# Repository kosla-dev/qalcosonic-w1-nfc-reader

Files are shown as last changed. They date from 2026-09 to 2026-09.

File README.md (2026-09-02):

# Qalcosonic W1 NFC Reader

A compact ESPHome-based NFC reader for the **Qalcosonic W1** water meter, built around a **Seeed Studio XIAO ESP32-C3**, **PN5180** ISO15693 reader and a custom adapter PCB.

The reader exposes water consumption, flow, temperature, battery state and meter diagnostics to Home Assistant without a camera or OCR pipeline.

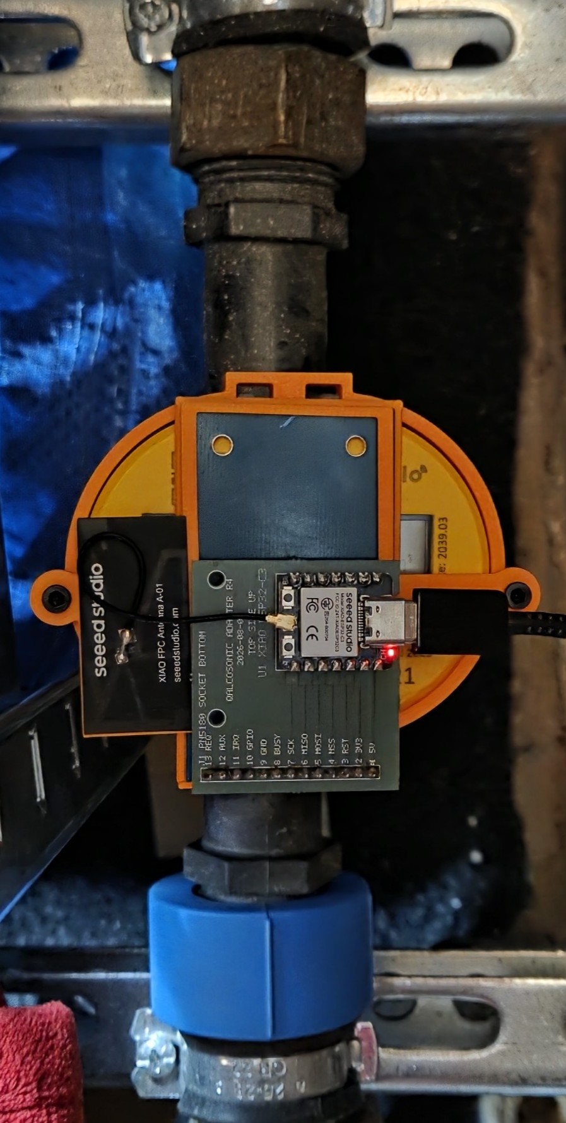
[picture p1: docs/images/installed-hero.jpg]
Installed Qalcosonic W1 NFC reader


## What you need

- Qalcosonic W1 water meter
- PN5180 NFC reader module
- Standard 2.54 mm male pin header strip for the PN5180 ↔ adapter PCB connection (usually included with the PN5180 module)
- Seeed Studio XIAO ESP32-C3
- Custom PN5180 ↔ XIAO adapter PCB
- Three printed R1.0 mechanical parts
- 2 × M3 × 8 mm pan-head screws

The current R1.0 mechanical design has been physically test-printed, assembled and used on a real Qalcosonic W1.

## Quick start

1. Order or manufacture the adapter PCB from [`hardware/`](hardware/).
2. Print the mechanical parts from [`mechanical/`](mechanical/).
3. Assemble the XIAO ESP32-C3, adapter PCB and PN5180.
4. Flash [`firmware/qalcosonic-w1-nfc-reader.yaml`](firmware/qalcosonic-w1-nfc-reader.yaml) with ESPHome.
5. Install the reader on the meter using the supplied R1.0 orientation.
6. Add the ESPHome device to Home Assistant.

Detailed instructions are under [`docs/`](docs/).

## Firmware

The production configuration uses ESPHome **2026.8.2 or newer** and the external [`dbmaxpayne/esphome_qalcosonicnfc`](https://github.com/dbmaxpayne/esphome_qalcosonicnfc) component pinned to:

```text
bed6773b803a7ebf71613585aad8a73376d38b8e
```

The meter is polled every **5 minutes**. Primary water data and important error states are enabled by default; lower-level diagnostic data remains disabled by default.

See [`firmware/`](firmware/) for the configuration and secrets template.

## Mechanical design

The clean-sheet R1.0 mount consists of:

1. meter collar / base
2. PN5180 carrier
3. upper retainer

The PN5180 PCB is retained with two M3 × 8 mm screws. All three printed parts are designed to print without slicer-generated supports.

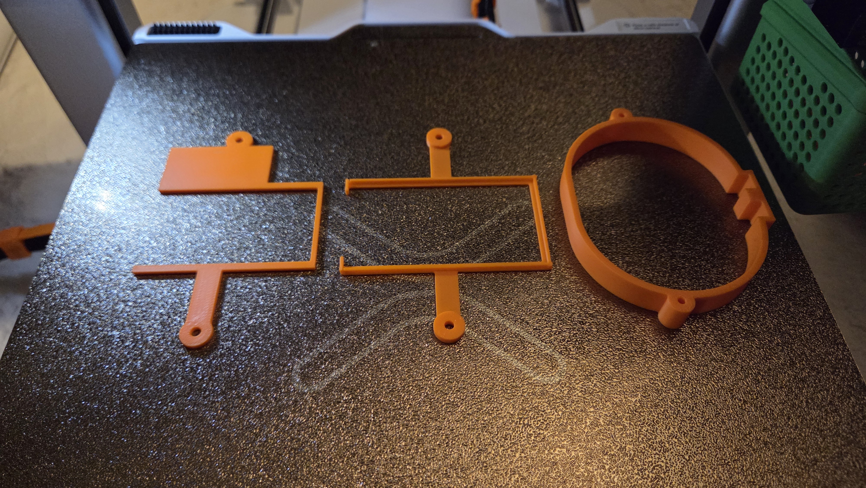
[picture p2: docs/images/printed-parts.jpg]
Printed R1.0 parts


Ready-to-print and editable files are under [`mechanical/`](mechanical/).

The ready-to-download R1.0 model is also available on [Printables](https://www.printables.com/model/1829911-qalcosonic-w1-pn5180-nfc-reader-mount).

## PCB

The custom 2-layer adapter PCB connects the XIAO ESP32-C3 directly to the PN5180. Gerber/Excellon files and an AISLER-ready ZIP are under [`hardware/`](hardware/).

PCB photographs are illustrative. The checked-in Revision 3 manufacturing files are the fabrication source of truth.

## Printing

Recommended starting point:

- 0.4 mm nozzle
- 0.20 mm layer height
- 3 walls
- 20% grid or gyroid infill
- supports: **OFF**
- PETG recommended for long-term installation
- PLA suitable for fit and function testing

See [`mechanical/README.md`](mechanical/README.md) for part orientation and package contents.

## Documentation

- [`docs/assembly.md`](docs/assembly.md) — assembly
- [`docs/wiring.md`](docs/wiring.md) — signal mapping
- [`docs/esphome-installation.md`](docs/esphome-installation.md) — ESPHome setup
- [`docs/home-assistant.md`](docs/home-assistant.md) — Home Assistant integration
- [`docs/troubleshooting.md`](docs/troubleshooting.md) — common checks

## Repository layout

```text
firmware/      ESPHome configuration and example secrets
hardware/      PCB manufacturing files and documentation
mechanical/    3D design source and production package
docs/          Build and installation documentation
LICENSES/      License texts and scope
```

## Support this project

If this project helped you, you can support future development on [Buy Me a Coffee](https://buymeacoffee.com/kosla).

## Licensing

This repository uses scoped licenses:

- firmware/configuration: **MIT**
- PCB and mechanical design assets: **CERN-OHL-P-2.0**
- documentation and project photographs: **CC BY 4.0**

The external `dbmaxpayne/esphome_qalcosonicnfc` dependency remains under its upstream **LGPL-2.1** license.

See [`LICENSE`](LICENSE), [`LICENSES/README.md`](LICENSES/README.md) and [`ATTRIBUTION.md`](ATTRIBUTION.md).

## Disclaimer

This project is provided **as-is**, without warranty of any kind.

Use and installation are entirely at your own risk. The project author is not responsible for damage to equipment, property, water meters or electronics, loss of data, incorrect meter readings, or other consequences resulting from building, installing or using this project.

Always follow applicable local regulations and the requirements of your water utility or meter owner. Do not interfere with metrology seals, certified measurement functions or utility-owned equipment.

This is an independent community project and is not affiliated with or endorsed by Axioma Metering, Seeed Studio, NXP, ESPHome or any utility provider.

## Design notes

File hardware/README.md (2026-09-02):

# Hardware

The reader uses a custom adapter PCB between the **PN5180** NFC module and a **Seeed Studio XIAO ESP32-C3**.

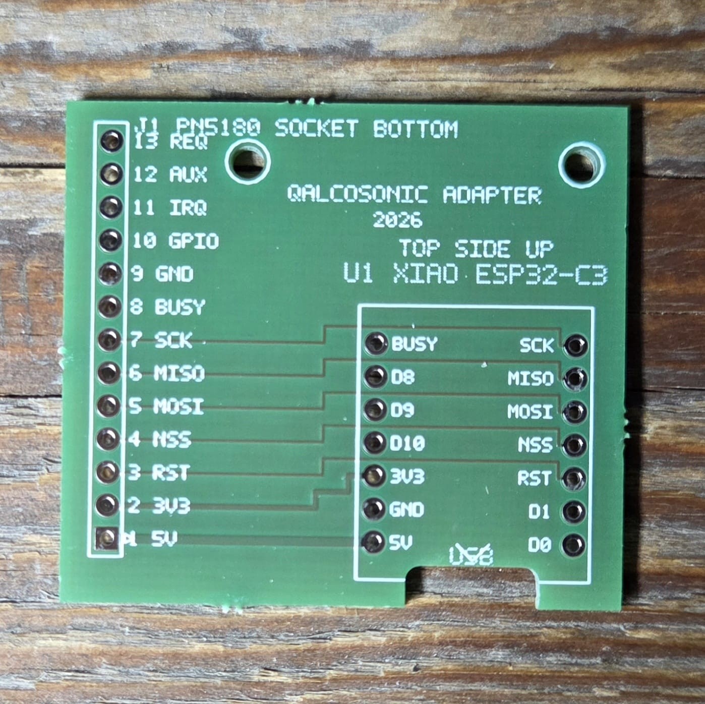
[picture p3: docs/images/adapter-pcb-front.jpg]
Adapter PCB front


> PCB photographs are illustrative. Use the checked-in Revision 3 manufacturing files for fabrication.

## Core hardware

- Seeed Studio XIAO ESP32-C3
- PN5180 NFC reader module
- Standard 2.54 mm male pin header strip for the PN5180 ↔ adapter PCB connection
- Custom 2-layer adapter PCB
- 3D-printed R1.0 meter mount

The pin header is usually included with the PN5180 module. If your module is supplied without one, use a standard 2.54 mm male pin header strip cut to the required length.

| Adapter PCB back | XIAO ESP32-C3 | PN5180 |
|---|---|---|
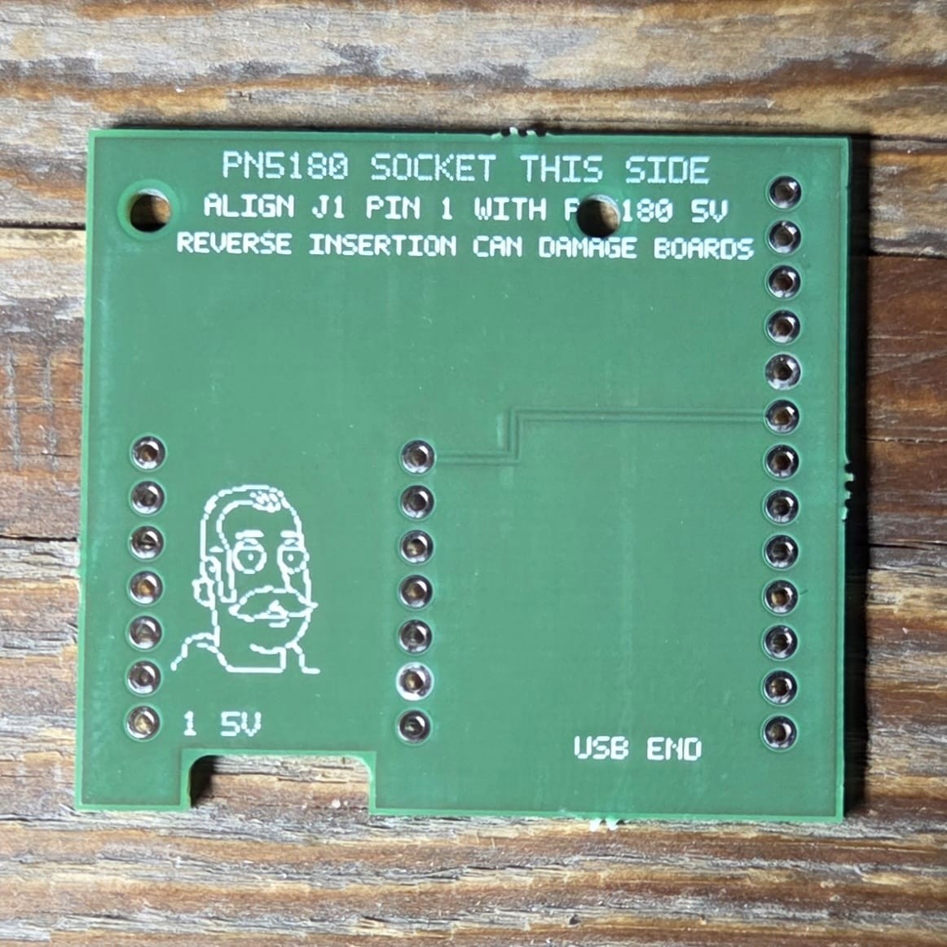
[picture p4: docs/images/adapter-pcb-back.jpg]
Adapter PCB back
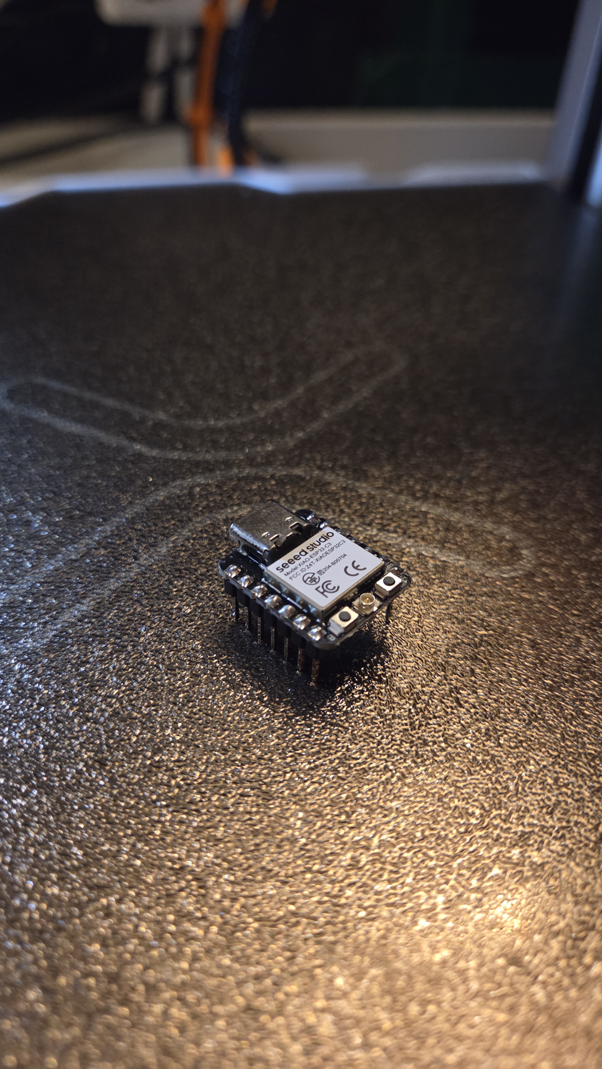
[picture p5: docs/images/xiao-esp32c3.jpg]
XIAO ESP32-C3
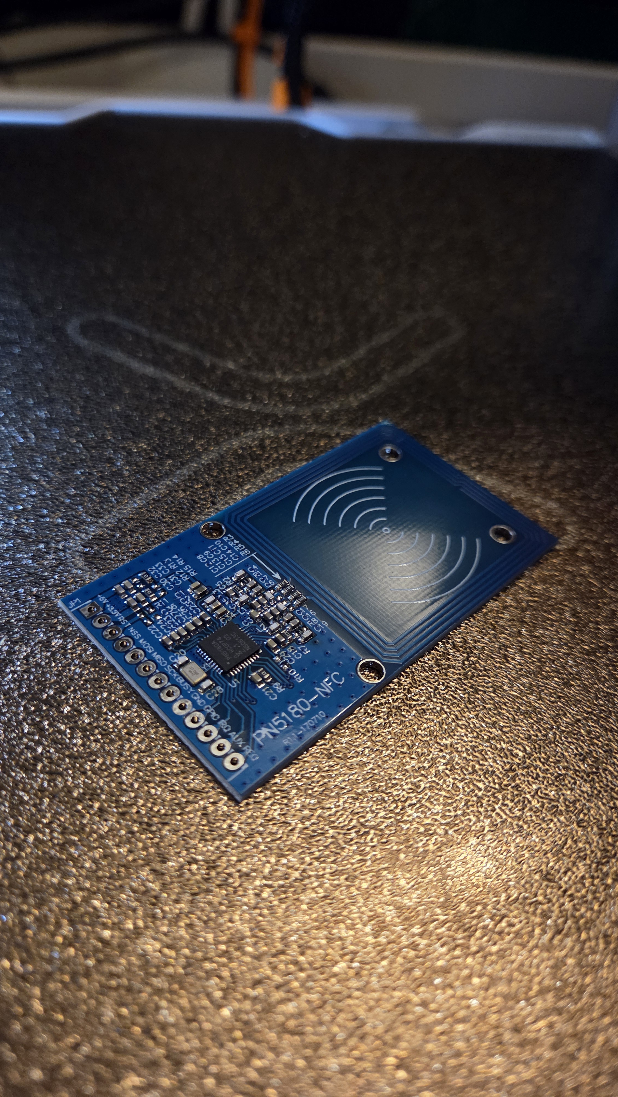
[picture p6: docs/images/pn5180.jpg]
PN5180
|  |  |  |

## Pin mapping

| Signal | XIAO ESP32-C3 |
|---|---:|
| PN5180 MOSI | GPIO6 |
| PN5180 MISO | GPIO7 |
| PN5180 SCK | GPIO21 |
| PN5180 NSS | GPIO5 |
| PN5180 BUSY | GPIO20 |
| PN5180 RST | GPIO4 |

This pinout matches the production ESPHome configuration under `firmware/`.

## PCB production specification

- Layers: 2
- PCB thickness: 1.6 mm
- Copper: 35 µm
- Surface finish: lead-free HASL
- Solder mask: green
- Silkscreen: white
- Stencil: not required for the hand-assembled build

## Manufacturing files

- `hardware/gerbers/` — complete Gerber/Excellon fabrication set
- `hardware/manufacturing/qalcosonic-w1-nfc-reader-pcb-rev3-aisler.zip` — AISLER-ready archive

See [`manufacturing/README.md`](manufacturing/README.md) for the fabrication notes.

Always inspect the board-house preview before placing an order.

## Assembly notes

Before applying power:

1. Inspect solder joints for bridges.
2. Verify 3.3 V and GND are not shorted.
3. Confirm the XIAO and PN5180 orientation.
4. Check signal routing against the pin table above.
5. Power the board on the bench and check for abnormal heating before installing it on the meter.

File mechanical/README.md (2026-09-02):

# Mechanical design

The production design is a clean-sheet, three-part mount for the Qalcosonic W1 and PN5180.

## Parts

### Base / meter collar

Clips around the Qalcosonic W1 and fixes the orientation of the complete reader assembly.

### PN5180 carrier

Locates the 70 × 39 mm PN5180 PCB by its perimeter while keeping the antenna area open.

### Upper retainer

Clamps the PN5180 gently at the PCB edges using two M3 screws and provides the electronics mounting land.

The side wing on the retainer also provides a convenient mounting surface for the external XIAO ESP32-C3 Wi-Fi antenna. The antenna can be attached flat to the wing using its adhesive backing or thin double-sided tape, as shown in the installed project photographs.

## Key dimensions

- Collar engagement: 11.0 mm
- PN5180 PCB reference outline: 70.0 × 39.0 mm
- PCB thickness used for the design: 1.65 mm
- Nominal PCB side clearance: 0.30 mm per side
- Nominal component-to-meter gap: 0.55 mm

## Editable source

The authoritative CadQuery source is:

```text
mechanical/source/qalcosonic_w1_pn5180_production_r1_0.py
```

It exports the base, carrier and retainer geometry.

## Ready-to-print file

The three-part print plate is:

```text
mechanical/3mf/qalcosonic-w1-pn5180-production-r1.0.3mf
```

## Production package

A user-facing package is included as:

```text
mechanical/qalcosonic-w1-pn5180-production-r1.0.zip
```

It contains:

```text
QALCOSONIC_W1_PN5180_R1.0_PRINT_PLATE.3mf
BASE.step
CARRIER.step
RETAINER.step
README.md
```

The 3MF is ready to print. STEP files are included for inspection and modification. The CadQuery source and validation data are also available in the repository.

## Print orientation

- Base: upright with the collar axis in Z
- Carrier: flat
- Retainer: flat
- Supports: **OFF**
- Brim: normally **OFF**

## Recommended settings

- PETG recommended for long-term installation
- PLA suitable for fit/function testing
- 0.4 mm nozzle
- 0.20 mm layer height
- 3 walls
- 5 top / 5 bottom layers
- 20% grid or gyroid infill
- Supports OFF

## Hardware

- 2 × M3 × 8 mm pan-head screws
- No nuts required

Tighten only until the retainer is seated. Do not bow the PN5180 PCB.

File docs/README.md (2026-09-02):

# Documentation

Build and installation documentation for the Qalcosonic W1 NFC Reader.

- [`assembly.md`](assembly.md) — electronics and mechanical assembly
- [`wiring.md`](wiring.md) — XIAO ESP32-C3 ↔ PN5180 signal mapping
- [`esphome-installation.md`](esphome-installation.md) — ESPHome setup and flashing
- [`home-assistant.md`](home-assistant.md) — Home Assistant integration and entity notes
- [`troubleshooting.md`](troubleshooting.md) — common failure modes and checks
- `images/` — project photographs

The documentation is written for the R1.0 production mechanical design.

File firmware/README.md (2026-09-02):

# Firmware

The production firmware is an ESPHome configuration for the **Seeed Studio XIAO ESP32-C3** and PN5180 NFC reader.

## Files

- `qalcosonic-w1-nfc-reader.yaml` — sanitized production configuration
- `secrets.example.yaml` — template for local ESPHome secrets

The configuration uses DHCP by default. If you want a static address, assign one in your router or add your own `manual_ip:` block locally.

## Requirements

- ESPHome **2026.8.2 or newer**
- Seeed Studio XIAO ESP32-C3
- PN5180 module
- Custom adapter PCB or equivalent wiring

## External component

The configuration uses:

`https://github.com/dbmaxpayne/esphome_qalcosonicnfc`

Pinned revision:

```text
bed6773b803a7ebf71613585aad8a73376d38b8e
```

Pinning the dependency keeps builds reproducible.

## Setup

1. Copy `qalcosonic-w1-nfc-reader.yaml` into your ESPHome configuration directory.
2. Copy `secrets.example.yaml` to `secrets.yaml`.
3. Replace all placeholder values in `secrets.yaml`.
4. Compile and flash the XIAO ESP32-C3.
5. Add the discovered ESPHome device to Home Assistant.

The configuration uses `Europe/Helsinki` for the optional meter timepoint sensor. Change it locally if needed.

See [`../docs/wiring.md`](../docs/wiring.md) for the pin mapping and [`../docs/esphome-installation.md`](../docs/esphome-installation.md) for flashing instructions.

## Production behavior

- Meter read interval: **300 s / 5 min**
- Five consecutive read failures are allowed before measurement sensors are treated as unavailable
- `Force Sensor Update` button for manual reads
- ESP32 diagnostics grouped into a separate Home Assistant device
- Primary water data and important error flags enabled by default
- Secondary/raw meter data and most network-identification diagnostics disabled by default
- Normal logging level: `INFO`

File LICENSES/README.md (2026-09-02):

# Licenses

This repository uses different licenses for software, open-hardware design material and documentation/media.

Copyright for original project material is held by **kosla-dev** unless a file states otherwise.

## Firmware — MIT

Original project software/configuration under `firmware/` is licensed under the **MIT License**, including:

- `firmware/qalcosonic-w1-nfc-reader.yaml`
- `firmware/secrets.example.yaml`

License text: [`MIT.txt`](MIT.txt)

The external `dbmaxpayne/esphome_qalcosonicnfc` component is not relicensed here and remains under its upstream LGPL-2.1 terms.

## PCB and mechanical design — CERN-OHL-P-2.0

Original hardware design and fabrication/print assets are licensed under the **CERN Open Hardware Licence Version 2 — Permissive (CERN-OHL-P-2.0)**.

This includes:

- `hardware/` fabrication assets, including Gerber/Excellon data and production archives
- `mechanical/source/`
- `mechanical/3mf/`
- mechanical production archives and validation data

Human-readable README/documentation files are covered by CC BY 4.0 instead.

License text: [`CERN-OHL-P-2.0.txt`](CERN-OHL-P-2.0.txt)

## Documentation and photographs — CC BY 4.0

Original project documentation and photographs are licensed under **Creative Commons Attribution 4.0 International (CC BY 4.0)**.

This includes the root documentation files, `docs/`, documentation README files and the original photographs under `docs/images/`.

Suggested attribution:

> Qalcosonic W1 NFC Reader project by kosla-dev — CC BY 4.0

License text: [`CC-BY-4.0.txt`](CC-BY-4.0.txt)

## Third-party dependency

The firmware uses [`dbmaxpayne/esphome_qalcosonicnfc`](https://github.com/dbmaxpayne/esphome_qalcosonicnfc), pinned to:

```text
bed6773b803a7ebf71613585aad8a73376d38b8e
```

The component remains under its upstream **LGPL-2.1** license and is not vendored into this repository.

See [`../ATTRIBUTION.md`](../ATTRIBUTION.md) for attribution details.

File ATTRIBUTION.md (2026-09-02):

# Attribution

This project contains original hardware, ESPHome configuration, documentation, original photographs and a clean-sheet mechanical design, together with one third-party open-source ESPHome dependency.

## Original project material

Original project material is copyright **kosla-dev, 2026** and is released under the scoped licenses described in [`LICENSES/README.md`](LICENSES/README.md):

- firmware/configuration: **MIT**
- PCB and mechanical design source/fabrication assets: **CERN-OHL-P-2.0**
- documentation and original project photographs: **CC BY 4.0**

These licenses apply only to original project material within their documented scope.

## ESPHome Qalcosonic NFC component

The firmware configuration uses the external [`dbmaxpayne/esphome_qalcosonicnfc`](https://github.com/dbmaxpayne/esphome_qalcosonicnfc) component by **dbmaxpayne**.

The production configuration pins the dependency to:

```text
bed6773b803a7ebf71613585aad8a73376d38b8e
```

The upstream repository is licensed under the **GNU Lesser General Public License v2.1 (LGPL-2.1)**. The component remains an external dependency and is not claimed as original work of this repository.

No copy of the component source is vendored here; ESPHome retrieves the pinned upstream revision during the build. Nothing in this repository's MIT license changes the upstream LGPL-2.1 terms.

The upstream component includes PN5180 driver code based on the [`ATrappmann/PN5180-Library`](https://github.com/ATrappmann/PN5180-Library) by **Andreas Trappmann**, licensed under **LGPL-2.1**. See the upstream component for the applicable copyright and license notices.

## Mechanical design

The current Production R1.0 geometry — meter collar/base, PN5180 carrier and upper retainer — was designed parametrically **from scratch** for this project.

The production hardware design assets are released under **CERN-OHL-P-2.0**.

## Custom adapter PCB

The PN5180 ↔ Seeed Studio XIAO ESP32-C3 adapter PCB is original project hardware. Its design/fabrication assets under `hardware/` are released under **CERN-OHL-P-2.0**. Human-readable documentation is CC BY 4.0.

## Documentation and photographs

Project-authored documentation and the photographs under `docs/images/` are original project material released under **CC BY 4.0**.

Suggested attribution:

> Qalcosonic W1 NFC Reader project by kosla-dev

## Product names and trademarks

Qalcosonic, Axioma, PN5180, ESPHome and Seeed Studio product names are used only to identify compatibility and the components used in the build.

This project is independent and is not affiliated with or endorsed by Axioma Metering, Seeed Studio, NXP or the ESPHome project.

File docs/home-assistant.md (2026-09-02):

# Home Assistant

The reader integrates through the standard ESPHome integration.

## Add the device

After the first successful ESPHome boot and Wi-Fi connection, Home Assistant should discover the device automatically. If it does not, add it manually through **Settings → Devices & services → Add integration → ESPHome** and enter the reader's hostname or IP address.

The default firmware configuration uses the hostname:

`qalcosonic-w1-nfc-reader-xiao`

## Entity reference

The tables below list the entities exposed by the production configuration in [`firmware/qalcosonic-w1-nfc-reader.yaml`](../firmware/qalcosonic-w1-nfc-reader.yaml).

Home Assistant entity IDs are generated from the device and entity names and may change if you rename the device. The names below are the display names defined by the shipped configuration.

### Primary water data

These entities are enabled by default.

| Entity | Type | Description |
|---|---|---|
| **Water Consumption** | Sensor | Cumulative water volume in m³ |
| **Water Flow** | Sensor | Current water flow in m³/h |
| **Water Temperature** | Sensor | Water temperature reported by the meter |
| **Battery Level** | Sensor | Meter battery level |
| **Consecutive Errors** | Sensor | Consecutive NFC/read error count |

### Secondary water data

These entities are available but disabled by default to keep the normal entity list clean.

| Entity | Type | Default | Description |
|---|---|---|---|
| **External Temperature** | Sensor | Disabled | External temperature value reported by the meter |
| **Volume (Only Positive)** | Sensor | Disabled | Positive-direction water volume |
| **Volume (Only Negative)** | Sensor | Disabled | Negative-direction water volume |

### Meter warnings and errors

The most useful warning entities are enabled by default.

| Entity | Type | Default | Description |
|---|---|---|---|
| **Leakage** | Binary sensor | Enabled | Meter leakage warning |
| **Pipe Burst** | Binary sensor | Enabled | Burst / unusually high-flow warning |
| **Low Battery Warning** | Binary sensor | Enabled | Meter low-battery warning |
| **Hardware Failure** | Binary sensor | Enabled | Meter hardware-failure flag |
| **Software Failure** | Binary sensor | Enabled | Meter software-failure flag |
| **No Flow Sensor Signal** | Binary sensor | Enabled | No flow-sensor signal warning |
| **Reverse Flow** | Binary sensor | Enabled | Reverse-flow warning |
| **Reconfiguration Warning** | Binary sensor | Disabled | Meter reconfiguration warning |
| **No Consumption** | Binary sensor | Disabled | No-consumption warning |
| **Damage of Meter Housing** | Binary sensor | Disabled | Meter-housing damage warning |
| **Calculator Hardware Failure** | Binary sensor | Disabled | Calculator hardware-failure flag |
| **Optical Communication Error** | Binary sensor | Disabled | Optical communication error flag |
| **Excessive Flow Rate** | Binary sensor | Disabled | Excessive-flow-rate warning |
| **Freeze Alert** | Binary sensor | Disabled | Freeze warning |

### Meter information

These identification fields are disabled by default.

| Entity | Type | Default | Description |
|---|---|---|---|
| **Meter ID** | Sensor | Disabled | Meter identifier |
| **Serial Number** | Sensor | Disabled | Meter serial number |
| **Manufacturer ID** | Sensor | Disabled | Manufacturer identifier |
| **Meter Version** | Sensor | Disabled | Meter version information |

### Timing and raw diagnostics

These lower-level fields are disabled by default and are mainly useful for troubleshooting or protocol inspection.

| Entity | Type | Default | Description |
|---|---|---|---|
| **Timepoint** | Sensor | Disabled | Meter timepoint converted using `Europe/Helsinki` |
| **Timepoint Raw** | Sensor | Disabled | Raw meter timepoint value |
| **Operating Time** | Sensor | Disabled | Meter operating-time value |
| **On Time** | Sensor | Disabled | Meter on-time value |
| **Error Flags Raw** | Sensor | Disabled | Raw meter error flags |
| **M-Bus Raw Data** | Sensor | Disabled | Raw M-Bus payload/data exposed by the component |

### Controls

| Entity | Type | Default | Description |
|---|---|---|---|
| **Force Sensor Update** | Button | Enabled | Immediately requests a new meter read |
| **Restart** | Button | Enabled | Restarts the ESP32-C3 |

### ESP32-C3 diagnostics

The production configuration creates a separate **ESP32-C3 Diagnostics** device for hardware/network diagnostics.

| Entity | Type | Default | Description |
|---|---|---|---|
| **Temperature** | Sensor | Enabled | ESP32-C3 internal temperature |
| **WiFi Signal** | Sensor | Enabled | Wi-Fi signal strength |
| **Uptime** | Sensor | Enabled | ESP32-C3 uptime |
| **Status** | Binary sensor | Enabled | ESPHome connection/status state |
| **Reset Reason** | Text sensor | Enabled | Reason for the most recent ESP32 reset |
| **ESPHome Version** | Text sensor | Disabled | ESPHome firmware version |
| **IP Address** | Text sensor | Disabled | Current network IP address |
| **Connected SSID** | Text sensor | Disabled | Connected Wi-Fi SSID |
| **Connected BSSID** | Text sensor | Disabled | Connected access-point BSSID |
| **MAC Address** | Text sensor | Disabled | ESP32-C3 MAC address |

Disabled entities can be enabled from the Home Assistant device's entity settings when they are needed.

## Energy dashboard / water tracking

`Water Consumption` is the cumulative meter value and is the appropriate source when a Home Assistant water-consumption dashboard expects a monotonically increasing total.

If replacing an existing water-meter reader and preserving long-term statistics is important, verify the old and new readers show the same physical meter reading before switching the dashboard/statistics source. Do not reset or artificially zero the meter value during migration.

## Manual read

The ESPHome device exposes a **Force Sensor Update** button. Use it to trigger an immediate read while testing antenna placement or after mechanical changes.

## Expected update interval

The production configuration polls the meter every **300 seconds (5 minutes)**. This is intentional; water-meter NFC data does not need high-frequency polling for normal Home Assistant use.

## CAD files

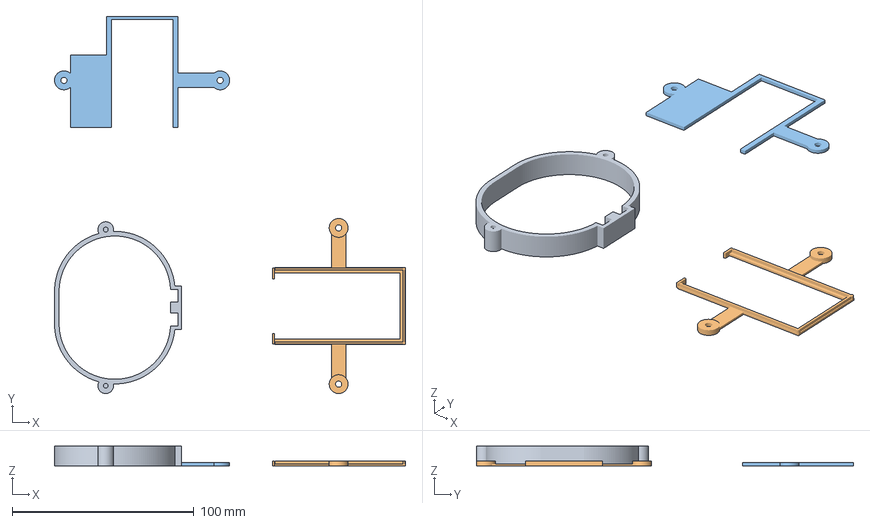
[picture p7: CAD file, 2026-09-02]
mechanical/3mf/qalcosonic-w1-pn5180-production-r1.0.3mf
193.2 x 207.6 x 11.0 mm
01_COLLAR_BASE
02_OPEN_PCB_CARRIER
03_OPEN_UPPER_RETAINER_WITH_C3_PAD

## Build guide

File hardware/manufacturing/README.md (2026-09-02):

# PCB manufacturing

The custom adapter PCB is prepared as an AISLER-compatible production package.

## Production specification

- 2 copper layers
- 1.6 mm board thickness
- 35 µm outer copper
- lead-free HASL finish
- green solder mask
- white silkscreen
- no stencil required for the hand-assembled build

## Revision 3

Revision 3 is the current production PCB revision.

## Production files

The complete board-house file set is checked into:

```text
hardware/gerbers/
```

It contains the board outline, top and bottom copper, solder masks, silkscreens and plated/non-plated drill data.

These checked-in Gerber/Excellon files are the PCB production source of truth.

## AISLER archive

The ready-to-upload archive is:

```text
hardware/manufacturing/qalcosonic-w1-nfc-reader-pcb-rev3-aisler.zip
```

You can upload this ZIP directly to AISLER or create an archive from the exact files under `hardware/gerbers/`.

## Before ordering

Always inspect the board-house preview, especially:

1. board outline and drill locations
2. top and bottom copper
3. solder-mask openings
4. top silkscreen orientation
5. bottom silkscreen orientation

PCB photographs elsewhere in the repository are illustrative; use the Revision 3 production files when ordering boards.

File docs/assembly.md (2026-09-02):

# Assembly

The production mechanical design consists of three printed parts:

1. **Base / meter collar**
2. **PN5180 carrier**
3. **Upper retainer**

> **Safety and responsibility:** Build and install this project at your own risk. Verify applicable local regulations and the requirements of your water utility or meter owner before installation. Do not disturb metrology seals, certified measurement functions or utility-owned equipment.

## Required parts

- Seeed Studio XIAO ESP32-C3
- PN5180 NFC reader
- custom adapter PCB
- R1.0 printed base / meter collar
- printed PN5180 carrier
- printed upper retainer
- 2 × M3 × 8 mm pan-head screws

Do not use a screw length that bottoms out before the retainer is seated or causes the PN5180 PCB to bow.

## 1. Assemble the electronics

1. Solder the Seeed Studio XIAO ESP32-C3 and PN5180 connections to the custom adapter PCB.
2. Inspect all solder joints for bridges or incomplete joints.
3. Check that 3.3 V, 5 V and GND are not shorted.
4. Confirm the XIAO and PN5180 orientation before applying power.
5. Power the assembly on the bench and verify that no component becomes abnormally hot.
6. Flash the production ESPHome configuration and confirm that the device connects normally.

## 2. Install the PN5180 in the carrier

1. Place the PN5180 module into the printed carrier.
2. Confirm that the PCB sits flat and no component or solder joint is pressed by the printed part.
3. Place the upper retainer over the PCB edge bands.
4. Insert the two M3 × 8 mm screws.
5. Tighten evenly only until the retainer is seated.
6. Confirm that the PN5180 PCB remains flat.
7. Attach the external XIAO ESP32-C3 Wi-Fi antenna flat to the side wing on the retainer using the antenna's adhesive backing or thin double-sided tape. The installed project photographs show the intended placement.

No nuts are required.

## 3. Install the reader on the Qalcosonic W1

1. Use the supplied R1.0 base / collar orientation.
2. Fit the collar onto the meter without forcing it over the meter protrusions.
3. Confirm that the modeled reliefs clear the meter correctly.
4. Keep the carrier and PN5180 in the orientation defined by the R1.0 assembly.
5. Check that the electronics and solder joints do not contact the meter body.
6. Confirm that USB access to the XIAO ESP32-C3 remains practical.

Do not mirror or arbitrarily rotate the printed assembly. NFC performance depends on the complete installed antenna position.

## 4. Functional check

After assembly:

1. Power the reader.
2. Open the ESPHome logs.
3. Confirm that `Inventory successful` appears on a normal read cycle.
4. Confirm that meter data is decoded and published to Home Assistant.
5. Verify that `Consecutive Errors` returns to `0` after successful reads.
6. Check that the PN5180 PCB remains flat and securely retained.

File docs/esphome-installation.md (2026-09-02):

# ESPHome installation

## Requirements

- ESPHome 2026.8.2 or newer
- Seeed Studio XIAO ESP32-C3
- PN5180 module connected through the project adapter PCB
- Wi-Fi credentials
- Home Assistant is optional but is the primary integration target

## Configuration

Copy `firmware/qalcosonic-w1-nfc-reader.yaml` to your ESPHome configuration directory and create a `secrets.yaml` based on `firmware/secrets.example.yaml`.

Required secrets:

- `wifi_ssid`
- `wifi_password`
- `fallback_password`
- `api_key`
- `ota_password`

The configuration uses DHCP by default.

The external component is pinned to:

`bed6773b803a7ebf71613585aad8a73376d38b8e`

from:

`https://github.com/dbmaxpayne/esphome_qalcosonicnfc`

## First flash

1. Connect the XIAO ESP32-C3 over USB.
2. Open ESPHome Device Builder or use the ESPHome CLI.
3. Compile the configuration.
4. Flash over USB for the first installation.
5. Open logs immediately after boot.
6. Confirm Wi-Fi and API connectivity.
7. Wait for the Qalcosonic NFC component to scan the meter.

A successful read cycle should include lines similar to:

```text
Scanning for water meter...
Inventory successful
Getting water meter infos
Water Usage: ...
Water Temperature: ...
Battery Percentage: ...
```

Do not copy meter UID, meter ID or network addresses from another installation into your configuration.

## Updates

After the device has joined Wi-Fi, normal ESPHome OTA updates can be used.

The configuration reads the meter every 300 seconds. A `Force Sensor Update` button is also exposed for manual testing.

## Diagnostics

The firmware exposes diagnostic entities for:

- Wi-Fi signal
- ESP32 internal temperature
- uptime
- device status
- reset reason
- optional ESPHome / Wi-Fi information

These are useful when commissioning the hardware or investigating intermittent reads.

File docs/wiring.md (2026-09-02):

# Wiring

The production reader uses a custom adapter PCB between the Seeed Studio XIAO ESP32-C3 and PN5180 NFC module.

## PN5180 signal mapping

| PN5180 signal | XIAO ESP32-C3 |
|---|---:|
| MOSI | GPIO6 |
| MISO | GPIO7 |
| SCK | GPIO21 |
| NSS / CS | GPIO5 |
| BUSY | GPIO20 |
| RST | GPIO4 |

These assignments are the same values used by `firmware/qalcosonic-w1-nfc-reader.yaml`.

## Power

Use the custom adapter PCB as the wiring reference rather than free-wiring the modules. Before first power-up:

1. inspect the 3.3 V and GND rails for solder bridges;
2. verify continuity only where expected;
3. confirm the XIAO orientation;
4. confirm the PN5180 orientation;
5. apply power while watching for abnormal heating.

## SPI / NFC notes

The PN5180 is used as an ISO15693 frontend. Keep the antenna side facing the water meter and avoid adding unnecessary metal directly in the antenna area.

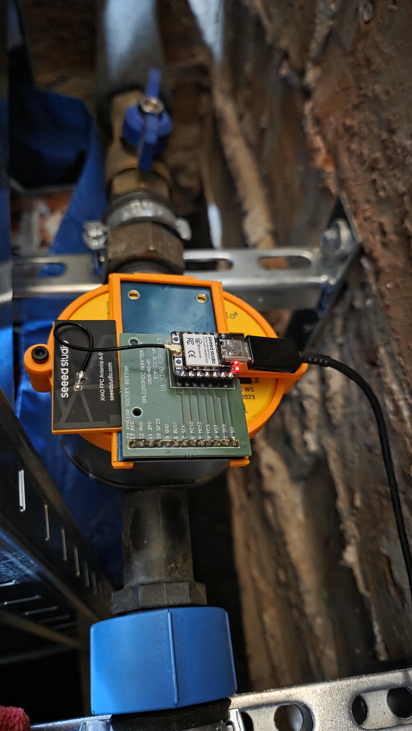
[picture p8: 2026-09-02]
docs/images/installed-closeup.jpg

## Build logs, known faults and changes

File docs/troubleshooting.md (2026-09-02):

# Troubleshooting

## Meter is not detected

If `Inventory successful` never appears:

1. confirm the PN5180 is powered;
2. verify MOSI/MISO/SCK/NSS/BUSY/RST against `docs/wiring.md`;
3. confirm the PN5180 antenna faces the meter;
4. install the mechanical holder in the supplied R1.0 orientation;
5. avoid unnecessary metal or thick material in the antenna area;
6. press **Force Sensor Update** and watch the ESPHome logs.

Do not mirror or arbitrarily rotate the holder. NFC performance depends on the installed antenna position.

## `qalcosonicnfc took a long time` warning

A single timing warning around a successful NFC read can occur because the component performs a complete PN5180 transaction and meter decode in one update operation.

If meter data is published correctly and reads remain stable, an isolated warning is not considered a failed read. Repeated timing warnings together with missed reads should be investigated.

## ESP32-C3 gets hot

Disconnect power immediately if the board becomes abnormally hot or there is an electrical smell.

Before reconnecting:

- inspect soldering for bridges;
- check 3.3 V to GND for an unintended short;
- inspect XIAO orientation;
- inspect the PN5180 and adapter board for damaged pads or excess solder.

Normal internal ESP32-C3 diagnostic temperature readings are not the same as a physically overheating board.

## Wi-Fi is weak

Meter reads happen locally, so Wi-Fi does not need to be exceptionally strong. Repeated API disconnects should still be addressed by improving AP placement or reducing obstruction around the XIAO antenna.

## Home Assistant does not show entities

1. confirm the ESPHome API connection succeeds;
2. verify the device appears under the ESPHome integration;
3. check whether the desired entity is disabled by default;
4. inspect ESPHome logs to confirm the source value is being read.

## Mechanical fit is wrong

Do not force the meter collar or bend the PN5180 PCB. Printer calibration, elephant-foot, material shrinkage and hardware variants can affect fit.

Use the source model to adjust tolerances if needed, but keep the documented installed orientation unless you also revalidate NFC operation on the meter.

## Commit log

2026-09-02 Initial release
    [qalcosonic-w1-pn5180-production-r1.0.3mf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]
2026-09-16 Update production PCB photos
